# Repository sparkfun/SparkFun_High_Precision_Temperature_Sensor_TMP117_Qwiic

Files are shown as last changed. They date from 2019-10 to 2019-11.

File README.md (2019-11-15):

SparkFun High Precision Temperature Sensor TMP117 (Qwiic)
========================================

SparkFun High Precision Temperature Sensor TMP117 (Qwiic) (https://www.sparkfun.com/products/15805)

[*SparkFun High Precision Temperature Sensor TMP117 (Qwiic) (SEN-15805)*](https://www.sparkfun.com/products/15805)

The TMP117 is a high precision temperature sensor with accuracy of up to +/-0.1 degrees Celsius (across the temperature range of -20°C to +50°Cs with no calibration) and an operating temperature range of -55°C to +150°C. It is NIST traceable and verified with equipment that is calibrated to ISO/IEC 17025 accredited standards. It has a very low power consumption with a supply range of 1.8V to 5.5V.

The TMP117 address can be changed with an external jumper to 4 different addresses. There are 4 different conversion modes that it can read from, with continuous conversion, shutdown, and one shot conversion. There is also digital offset for system correction, programmable temperature limits, general-purpose EEPROM, and selectable averaging.

Repository Contents
-------------------

* **/Documentation** - Data sheets, additional product information
* **/Hardware** - Eagle design files (.brd, .sch)
* **/Production** - Production panel files (.brd)

Documentation
--------------

* **[Installing an Arduino Library Guide](https://learn.sparkfun.com/tutorials/installing-an-arduino-library)** - Basic information on how to install an Arduino library.
* **[Library](https://github.com/sparkfun/SparkFun_TMP117_Arduino_Library)** - Arduino library for the SparkFun High Precision Temperature Sensor TMP117 (Qwiic).
* **[Hookup Guide](https://learn.sparkfun.com/tutorials/qwiic-tmp117-high-precision-digital-temperature-sensor-hookup-guide)** - Basic hookup guide for the SparkFun High Precision Temperature Sensor TMP117 (Qwiic).

Version History
---------------

* [SparkFun High Precision Temperature Sensor TMP117 (Qwiic)](https://www.sparkfun.com/products/15805) - SparkFun Reds
* [SparkX Qwiic TMP117](https://www.sparkfun.com/products/15413) - Initial product release under SparkX 

License Information
-------------------

This product is _**open source**_! 

Please review the LICENSE.md file for license information. 

If you have any questions or concerns on licensing, please contact technical support on our [SparkFun forums](https://forum.sparkfun.com/viewforum.php?f=152).

Distributed as-is; no warranty is given.

- Your friends at SparkFun.

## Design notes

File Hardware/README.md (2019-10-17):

SparkFun High Precision Temperature Sensor TMP117 (Qwiic) Design Files
=====================================

The .sch and .brd files hare are Eagle CAD schematic and PCB design files from SparkFun Electronics.
A freeware version of Eagle can be found [here](http://www.cadsoftusa.com/download-eagle/freeware/).

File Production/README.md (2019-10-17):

SparkFun High Precision Temperature Sensor TMP117 (Qwiic) Production Files
=========================================

These are the production files SparkFun uses for printing PCBs.

License Information
-------------------
This product is open source! 

The hardware is released under [Creative Commons ShareAlike 4.0 International](https://creativecommons.org/licenses/by-sa/4.0/).

Please use, reuse, and modify these files as you see fit. Please maintain attribution to SparkFun Electronics and release anything derivative under the same license.

Distributed as-is; no warranty is given.

- Your friends at SparkFun.

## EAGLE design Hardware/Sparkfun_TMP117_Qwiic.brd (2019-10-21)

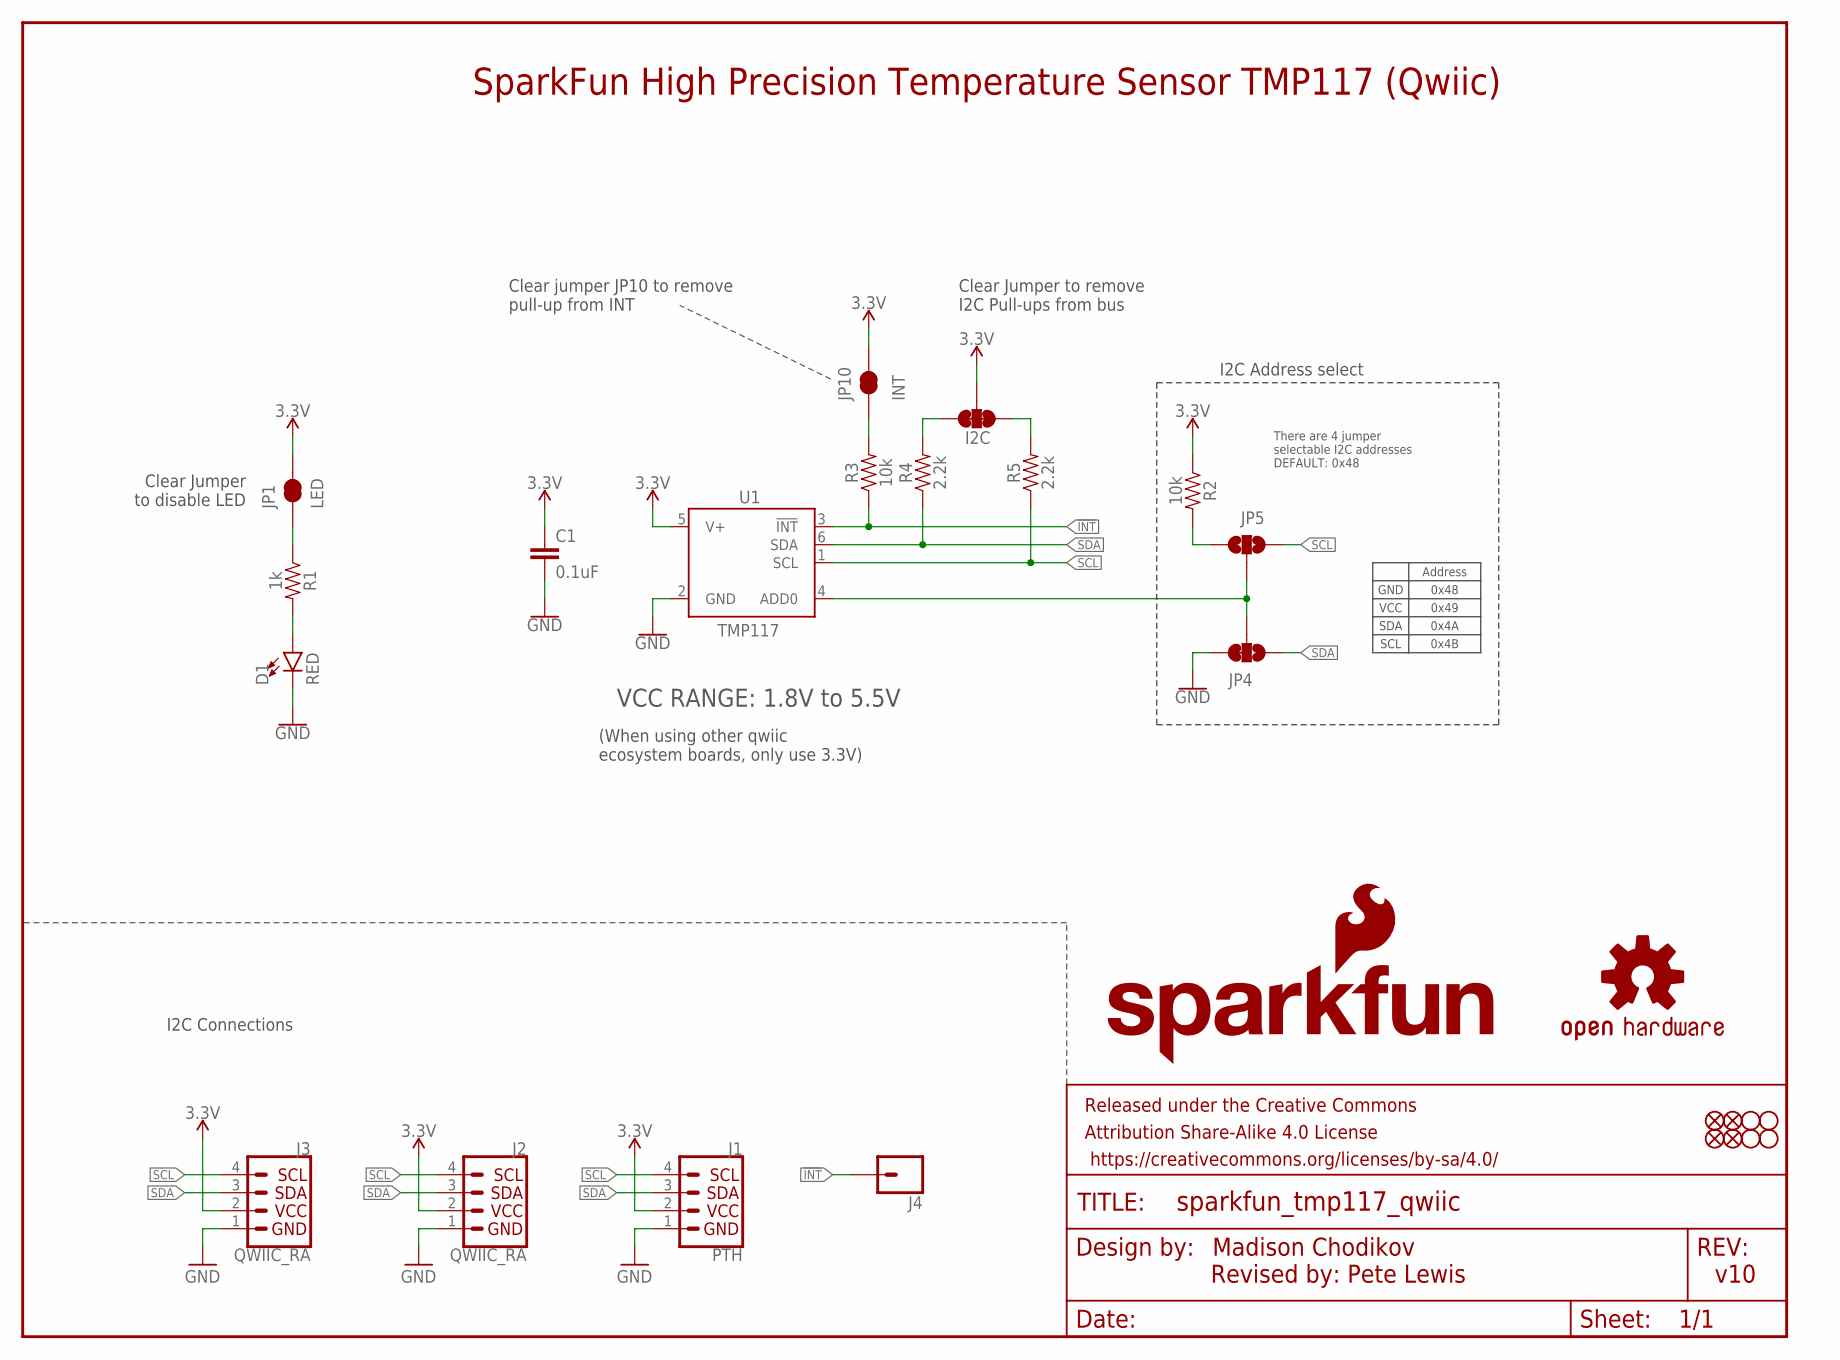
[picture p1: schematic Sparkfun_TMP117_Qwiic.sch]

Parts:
C1: 0.1uF; 0603
D1: RED; LED-0603
FD1, FD2, FD3, FD4: FIDUCIALUFIDUCIAL; FIDUCIAL-MICRO
FRAME1: FRAME-LETTER; CREATIVE_COMMONS
I2C: JUMPER-SMT_3_2-NC_TRACE_SILK; SMT-JUMPER_3_2-NC_TRACE_SILK
J1: PTH; 1X04_NO_SILK
J2, J3: QWIIC_RA; JST04_1MM_RA
J4: CONN_01PTH_NO_SILK_YES_STOP; 1X01_NO_SILK
JP1: LED; SMT-JUMPER_2_NC_TRACE_SILK
JP2, JP3, JP8, JP9: STAND-OFF
JP4: JUMPER-SMT_3_1-NC_TRACE_NO-SILK; SMT-JUMPER_3_1-NC_TRACE_NO-SILK
JP5: JUMPER-SMT_3_NO_NO_SILK; SMT-JUMPER_3_0-NO_TRACE_NO-SILK
JP10: INT; SMT-JUMPER_2_NC_TRACE_SILK
LOGO1: OSHW-LOGOMINI; OSHW-LOGO-MINI
LOGO4: SFE_LOGO_NAME_FLAME.1_INCH; SFE_LOGO_NAME_FLAME_.1
R1: 1k; 0603
R2, R3: 10k; 0603
R4, R5: 2.2k; 0603
U1: TMP117

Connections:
3.3V: C1.1, I2C.2, J1.2, J2.2, J3.2, JP1.2, JP10.2, R2.1, U1.5 (V+)
!INT: J4.1, R3.1, U1.3 (!INT)
ADD0: JP4.2, JP5.2, U1.4 (ADD0)
GND: C1.2, D1.C, J1.1, J2.1, J3.1, JP4.3, U1.2 (GND)
unnamed: D1.A, R1.2
unnamed: I2C.1, R5.2
unnamed: I2C.3, R4.2
unnamed: JP10.1, R3.2
unnamed: JP5.1, R2.2
unnamed: JP1.1, R1.1
SCL: J1.4, J2.4, J3.4, JP5.3, R5.1, U1.1 (SCL)
SDA: J1.3, J2.3, J3.3, JP4.1, R4.1, U1.6 (SDA)

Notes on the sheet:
I2C Connections
SparkFun High Precision Temperature Sensor TMP117 (Qwiic)
Madison Chodikov
Clear Jumper to remove I2C Pull-ups from bus
Clear jumper JP10 to remove pull-up from INT
v10
There are 4 jumper selectable I2C addresses DEFAULT: 0x48
Address
0x48
0x49
0x4A
0x4B
GND
VCC
SDA
SCL
I2C Address select
Clear Jumper to disable LED
Revised by: Pete Lewis
VCC RANGE: 1.8V to 5.5V
(When using other qwiic ecosystem boards, only use 3.3V)

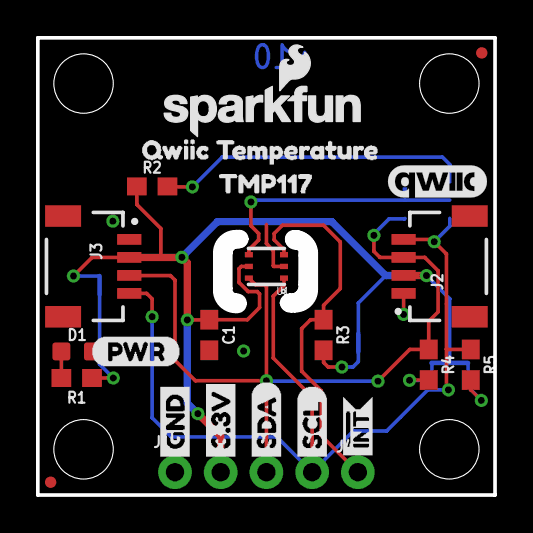
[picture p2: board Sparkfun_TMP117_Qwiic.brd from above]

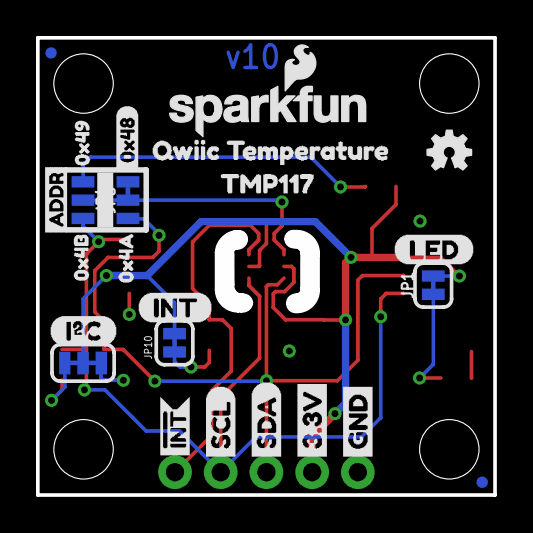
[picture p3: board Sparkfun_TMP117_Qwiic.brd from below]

Board: 2 copper layers, 25.4 x 25.4 mm, 53 parts (24 on the bottom side), 12 nets.

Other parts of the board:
LOGO2: SFE_LOGO_NAME_FLAME.1_INCH; SFE_LOGO_NAME_FLAME_.1
U$1, U$6: QWIIC_TEMPERATURE2
U$2: 0X491
U$3, U$11: INT#-[<-04
U$4, U$5: TMP1171
U$7: INT-()-04
U$8: LED0
U$9, U$12: SCL-[)
U$10, U$23: GND-04
U$13, U$14: SDA-[)
U$15: QWIIC_5.5MM
U$16: 0X4A2
U$17: 0X4B3
U$18: ADDR0
U$19, U$22: 3.3V
U$20: PWR-()-04
U$21: I_SUPER2_C-()-04
U$42: 0X480

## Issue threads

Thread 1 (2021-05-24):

Data sheet is actually an HTML file

anahata0108, 2021-05-24:
### Subject of the issue
The datasheet for the TMP117 is actually an HTML file (of a github page), not a PDF file

### Steps to reproduce
Try to view the [datasheet](https://github.com/sparkfun/SparkFun_High_Precision_Temperature_Sensor_TMP117_Qwiic/blob/master/Documentation/tmp117%20datasheet.pdf)

### Expected behavior
I expect to see a pretty datasheet telling me how the board works

### Actual behavior
The file is an HTML file of a github page

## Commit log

2019-10-17 initial commit - eagle changes too
    Changes to eagle files:
    -Adjusted dimensions and layout to 1"x1" (SPX version was .95"x.95")
    -SparkFun logo
    -Added version number
    -Added measures
    [Sparkfun_TMP117_Qwiic.brd, Sparkfun_TMP117_Qwiic.sch]
2019-10-17 more layout changes
    -moved to 4 jumpers on address select, to fully remove pull resisor when you cut trace. Previous version had pull down resistor permenantly in circuit, so it would be tied to SDA or SCL when those ad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
    -SCH cleanup
    -rerouting as necessary.
    -added LED bypass jumper
    [Sparkfun_TMP117_Qwiic.brd, Sparkfun_TMP117_Qwiic.sch]
2019-10-21 post design review changes
    -Added fiducials
    -added bottom two standoffs
    -switched to SFE logo with flame
    -moved I2C jumper to bottom
    -added outer box silk to address jumpers
    -moved pwr LED and jumper to make room for standoff
    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
    [Sparkfun_TMP117_Qwiic.brd, Sparkfun_TMP117_Qwiic.sch]
2019-10-21 parts to SFE libraries
    [Sparkfun_TMP117_Qwiic.brd, Sparkfun_TMP117_Qwiic.sch]
2019-10-21 1st run of checklist
    -version font type in schematic
    -silk width bumped up to 8 mils on a couple jumpers and the tmp117 package
    [Sparkfun_TMP117_Qwiic.brd, Sparkfun_TMP117_Qwiic.sch]
2019-10-21 checklist catches
    -remove package value on jumpers (SCH)
    -added VCC range text obj
    -fixed drc errors cause by unconnected dimension wires on special route out stuff near IC
    [Sparkfun_TMP117_Qwiic.brd, Sparkfun_TMP117_Qwiic.sch]

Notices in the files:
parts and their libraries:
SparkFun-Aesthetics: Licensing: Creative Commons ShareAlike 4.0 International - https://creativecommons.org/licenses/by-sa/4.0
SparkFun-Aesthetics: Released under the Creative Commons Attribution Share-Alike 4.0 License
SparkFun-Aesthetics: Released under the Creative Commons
